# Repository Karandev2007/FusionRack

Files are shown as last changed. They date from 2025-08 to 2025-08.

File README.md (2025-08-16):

<div align="center">
Title Image
</div>

----

<h3 align="center">Zentra / FusionRack</h3>

This is a modern design 2-piece server tower that features total of 4 in-built cooling fans with speed and direction control for more customization, and removable magnetic lid covers for front side.

## Features:
- In-built Cooling System with speed and direction control.
- Removable magnetic lids for easy hardware access.
- Designed for modern era
- Easily assemble or disassemble.
- 2 USFF or TFF mini pc space & a extra plate to attach as you wish for other broads.
--------





<p>


<p>
Fusion360_BamHtervRx
Fusion360_RbzkFNrMxT

----

### Circuit Diagram


----

## CAD


<p>

<p>

<p>

<p>

<p>

## BOM

| Components | Amount | Total Price | Buy Link |
|---|---|---|---|
| 5020 fans | 4 | $4.07 | [link](https://makerbazar.in/products/generic-axial-dc-cooling-fan-blowers?variant=46399947931888) |
| Neodymium Circular Magnet 3mm x 3mm | 24 | $2.20 | [link](https://makerbazar.in/products/neodymium-circular-magnet?variant=47451807875312) |
| 90° L Bracket Right Angle Shape Corner Stand | 8 | $0.92 | [link](https://makerbazar.in/products/right-angle-bracket-iron-angle-code-corner-stand?variant=46436990877936) |
| Ball Caster Wheels | 6 | $1.24 | [link](https://makerbazar.in/products/castor-wheels) |
| Low Cost USB-C wire | 1 | $0.45 | [link](https://makerbazar.in/products/generic-low-cost-type-c-usb-data-cable-black-white) |
| 5V LED strip | 1 | $2.27 | [link](https://amzn.in/d/drIJrVY) |
| PWM Fan Controller | 2 | $3.41 | [link](https://makerbazar.in/products/dc-6v-28v-6v-12v-24v-3a-pwm-dc-motor-speed-controller-forward-reverse-with-switch) |
| Ribbon Cable Wire | 2 | $0.87 | [link](https://makerbazar.in/products/multi-coloured-ribbon-cable-wire?variant=40914910281879) |
| Black Heat Shrink Sleeve Tube (2.5mm) | 1 | $0.091 | [link](https://makerbazar.in/products/heat-shrink?variant=19627635212384) |
| Type-C USB PCB Breakout Board | 1 | $0.22 | [link](https://makerbazar.in/products/type-c-usb-female-to-dip-pcb-breakout-board?variant=46337045299440) |
| KCD1 Big Rocker Switch | 3 | $0.24 | [link](https://makerbazar.in/products/big-rocker-switch-2-leg-spst?variant=46150295814384) |
| Steel Allen Socket Head Nut-Bolt M5 20mm | 2 | $2.17 | [link](https://makerbazar.in/products/stainless-steel-allen-head-nut-bolt-washer-set?variant=44137393783024) |
| Steel Allen Socket Head Nut-Bolt M5 25mm | 2 | $2.52 | [link](https://makerbazar.in/products/stainless-steel-allen-head-nut-bolt-washer-set?variant=45147658322160) |
| Steel Allen Socket Head Nut-Bolt M4 25mm | 1 | $1.09 | [link](https://makerbazar.in/products/stainless-steel-allen-head-nut-bolt-washer-set?variant=44137326838000) |
| buttonhead bolt M3 16mm | 4 | $0.39 | [link](https://novo3d.in/buttonhead-bolt-cs) |
| buttonhead bolt key M3 | 1 | $0.29 | [link](https://novo3d.in/allen-keys) |
| Brass Threaded Round Female Insert Nut | 4 | $0.23 | [link](https://makerbazar.in/products/brass-heat-set-threaded-round-female-insert-nut?variant=44435312083184) |
| JST-SM Male-Female Connectors | 4 | $0.41 | [link](https://makerbazar.in/products/jst-sm-male-and-female-connector-pair-with-wire?variant=47213255065840) |
| Miscs |  | $4 |

Shipping and extra fees: $0.46 (makerbazar) + $0.80 (nova3d) + $0.057 (amazon) = $1.317

Total: $28.44

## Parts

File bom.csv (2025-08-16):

Part Name | Quantity | Cost | Link
5020 fans | 4 | $4.07 | https://makerbazar.in/products/generic-axial-dc-cooling-fan-blowers?variant=46399947931888
Neodymium Circular Magnet 3mm x 3mm | 24 | $2.20 | https://makerbazar.in/products/neodymium-circular-magnet?variant=47451807875312
90° L Bracket Right Angle Shape Corner Stand | 8 | $0.92 | https://makerbazar.in/products/right-angle-bracket-iron-angle-code-corner-stand?variant=46436990877936
Ball Caster Wheels | 6 | $1.24 | https://makerbazar.in/products/castor-wheels
Low Cost USB-C wire | 1 | $0.45 | https://makerbazar.in/products/generic-low-cost-type-c-usb-data-cable-black-white
5V LED strip | 1 | $2.27 | https://amzn.in/d/drIJrVY
PWM Fan Controller | 2 | $3.41 | https://makerbazar.in/products/dc-6v-28v-6v-12v-24v-3a-pwm-dc-motor-speed-controller-forward-reverse-with-switch
Ribbon Cable Wire | 2 | $0.87 | https://makerbazar.in/products/multi-coloured-ribbon-cable-wire?variant=40914910281879
Black Heat Shrink Sleeve Tube (2.5mm) | 1 | $0.091 | https://makerbazar.in/products/heat-shrink?variant=19627635212384
Type-C USB PCB Breakout Board | 1 | $0.22 | https://makerbazar.in/products/type-c-usb-female-to-dip-pcb-breakout-board?variant=46337045299440
KCD1 Big Rocker Switch | 3 | $0.24 | https://makerbazar.in/products/big-rocker-switch-2-leg-spst?variant=46150295814384
Steel Allen Socket Head Nut-Bolt M5 20mm | 2 | $2.17 | https://makerbazar.in/products/stainless-steel-allen-head-nut-bolt-washer-set?variant=44137393783024
Steel Allen Socket Head Nut-Bolt M5 25mm | 2 | $2.52 | https://makerbazar.in/products/stainless-steel-allen-head-nut-bolt-washer-set?variant=45147658322160
Steel Allen Socket Head Nut-Bolt M4 25mm | 1 | $1.09 | https://makerbazar.in/products/stainless-steel-allen-head-nut-bolt-washer-set?variant=44137326838000
buttonhead bolt M3 16mm | 4 | $0.39 | https://novo3d.in/buttonhead-bolt-cs
buttonhead bolt key M3 | 1 | $0.29 | https://novo3d.in/allen-keys
Brass Threaded Round Female Insert Nut | 4 | $0.23 | https://makerbazar.in/products/brass-heat-set-threaded-round-female-insert-nut?variant=44435312083184
JST-SM Male-Female Connectors | 4 | $0.41 | https://makerbazar.in/products/jst-sm-male-and-female-connector-pair-with-wire?variant=47213255065840
Miscs | 1 | $4
Shipping and extra fees |  | $0.46 (makerbazar) + $0.80 (nova3d) + $0.057 (amazon)
Total |  | $28.44

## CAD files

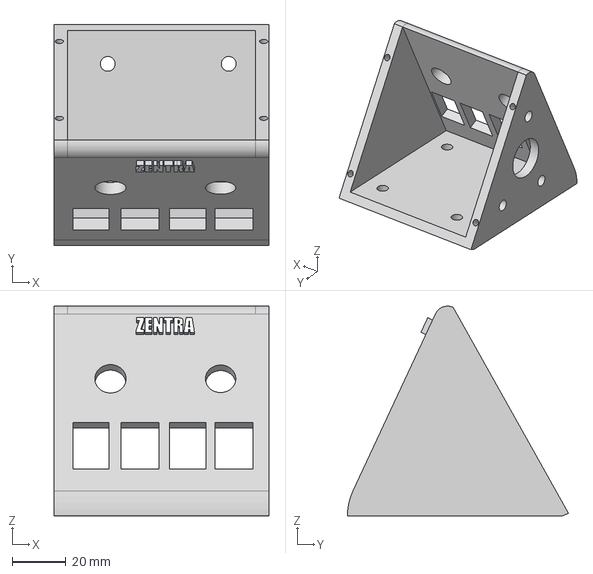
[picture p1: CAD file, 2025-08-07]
CAD/cp_mainbody.step
80.0 x 82.3 x 78.0 mm

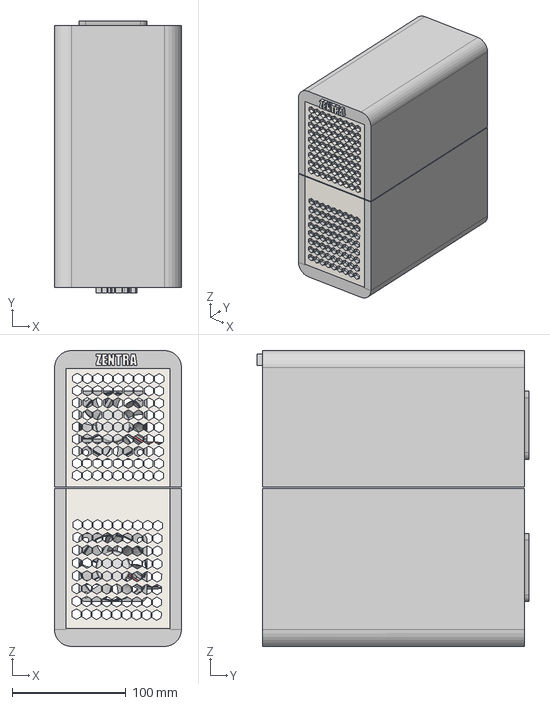
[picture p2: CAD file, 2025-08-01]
CAD/Zentra-assembled.step
111.7 x 239.1 x 259.9 mm

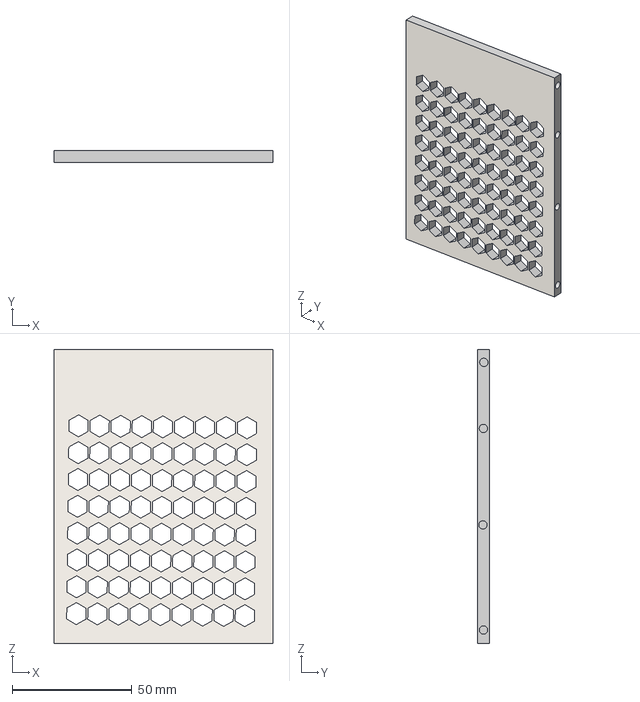
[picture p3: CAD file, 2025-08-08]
CAD/bottom_lid.step
91.5 x 5.00 x 123.0 mm

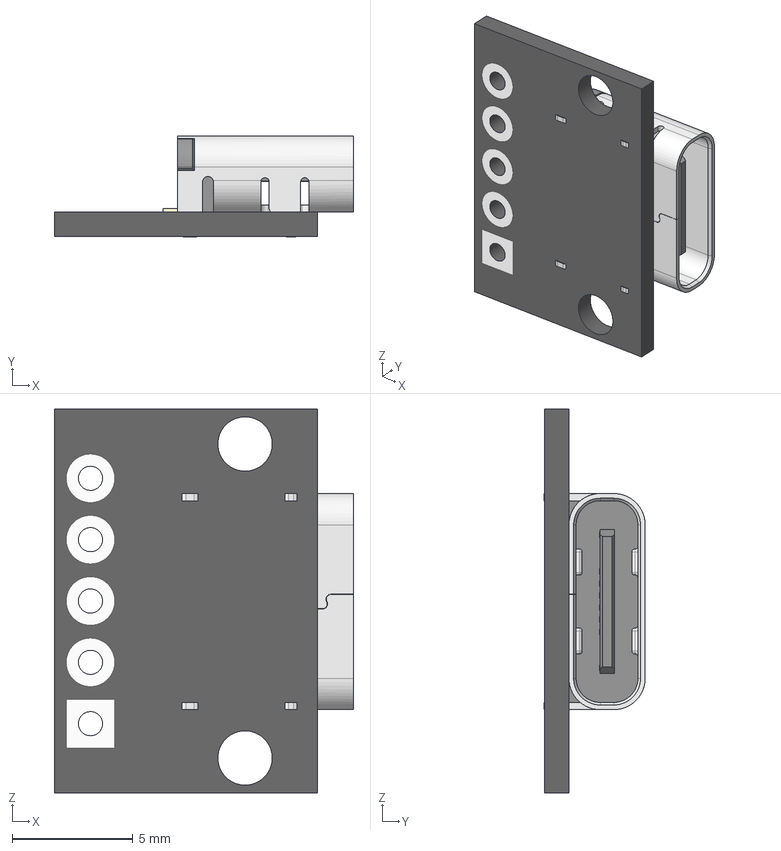
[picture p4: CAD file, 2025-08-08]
CAD/components/PCB USB-C.step
12.4 x 4.20 x 15.9 mm

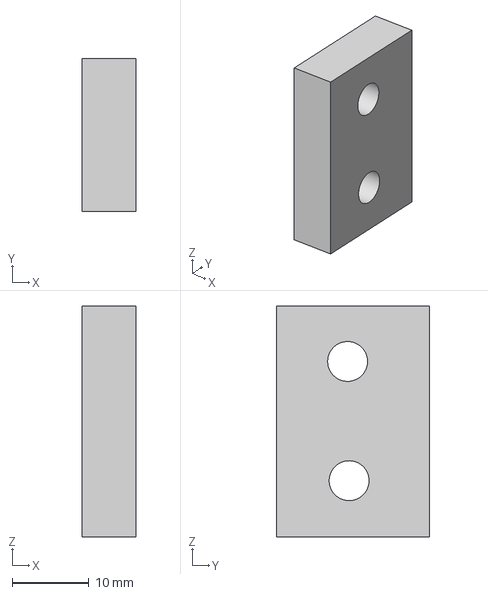
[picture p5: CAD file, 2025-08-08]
CAD/case_join_supports.step
7.00 x 20.0 x 30.1 mm

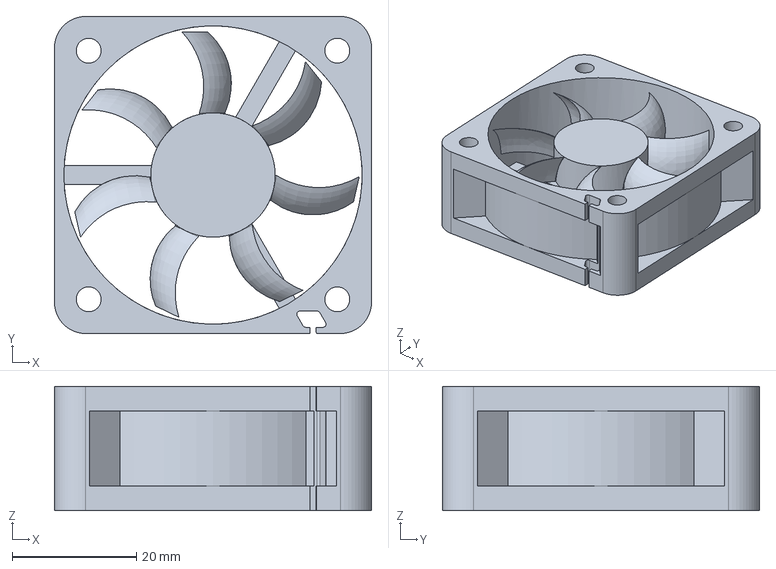
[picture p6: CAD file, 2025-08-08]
CAD/components/GDSTIME 50mm x 50mm x 20mm 12V Brushless Cooling Fan.step
51.0 x 51.0 x 20.0 mm

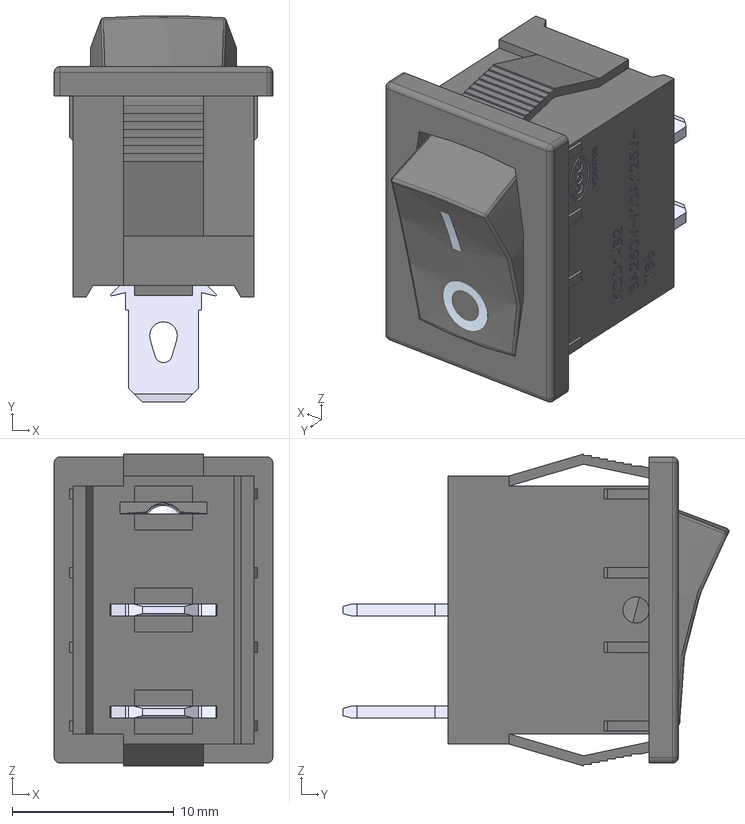
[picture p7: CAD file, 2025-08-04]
CAD/components/KCD1-B2-2P-Off.step
13.5 x 23.8 x 19.3 mm

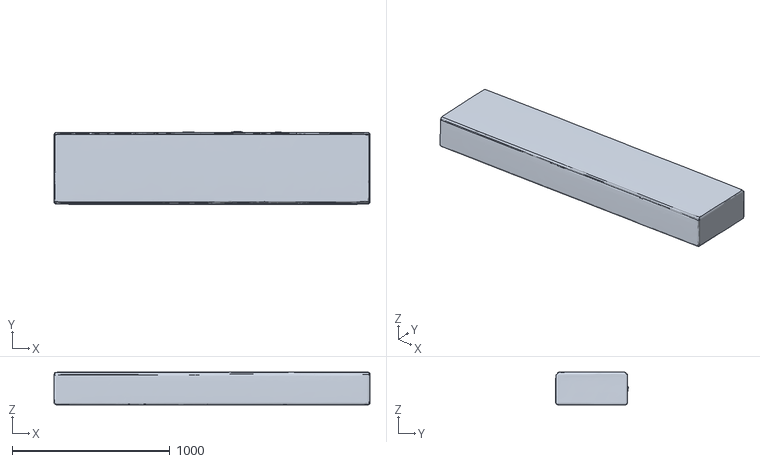
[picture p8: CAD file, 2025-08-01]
CAD/components/USB_Hub_Adapter.stl
2002.4 x 460.7 x 209.0

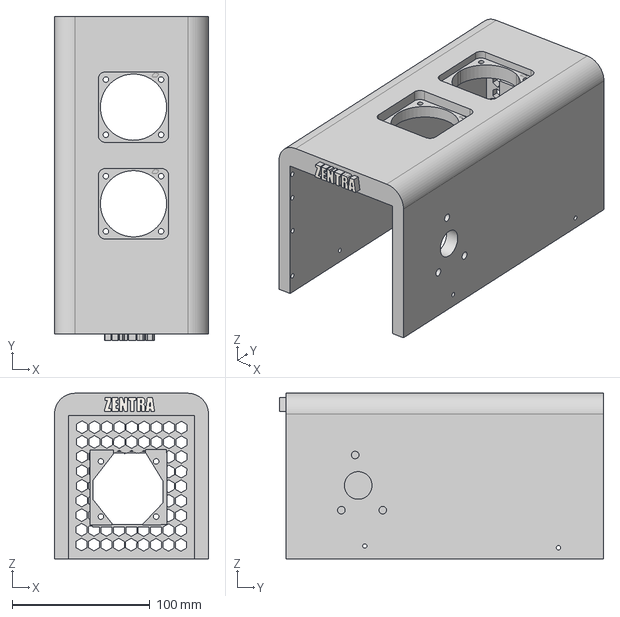
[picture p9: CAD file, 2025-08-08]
CAD/top_body.step
111.6 x 235.1 x 120.0 mm

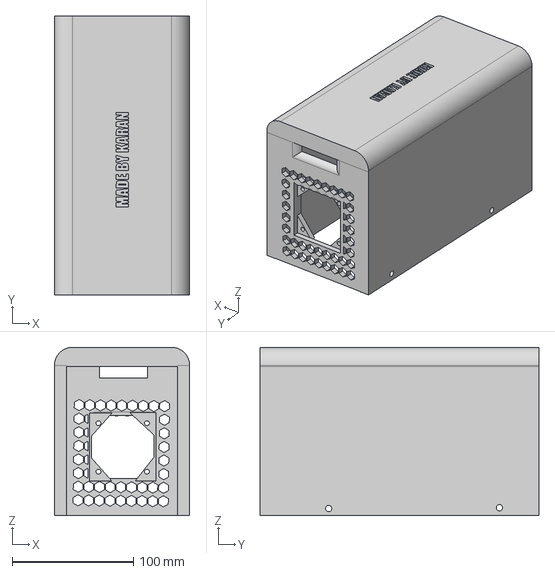
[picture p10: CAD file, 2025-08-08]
CAD/bottom_body.step
111.7 x 230.1 x 138.9 mm

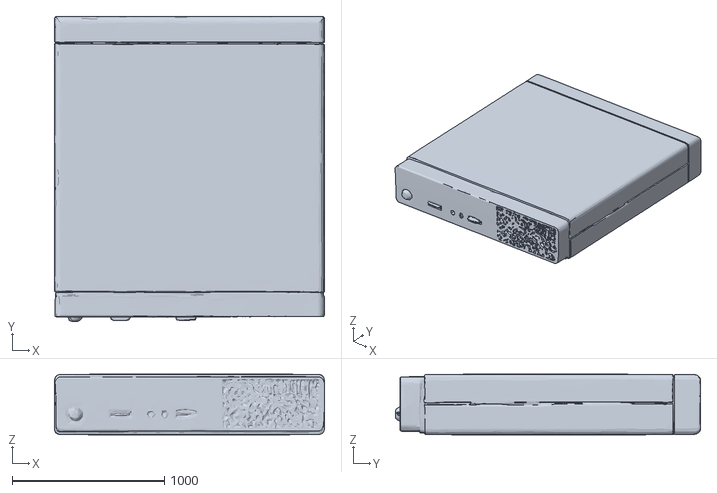
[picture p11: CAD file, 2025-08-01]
CAD/components/ThinkCentre_Mini_Desk_0727185635_texture.stl
1772.3 x 2003.6 x 398.2

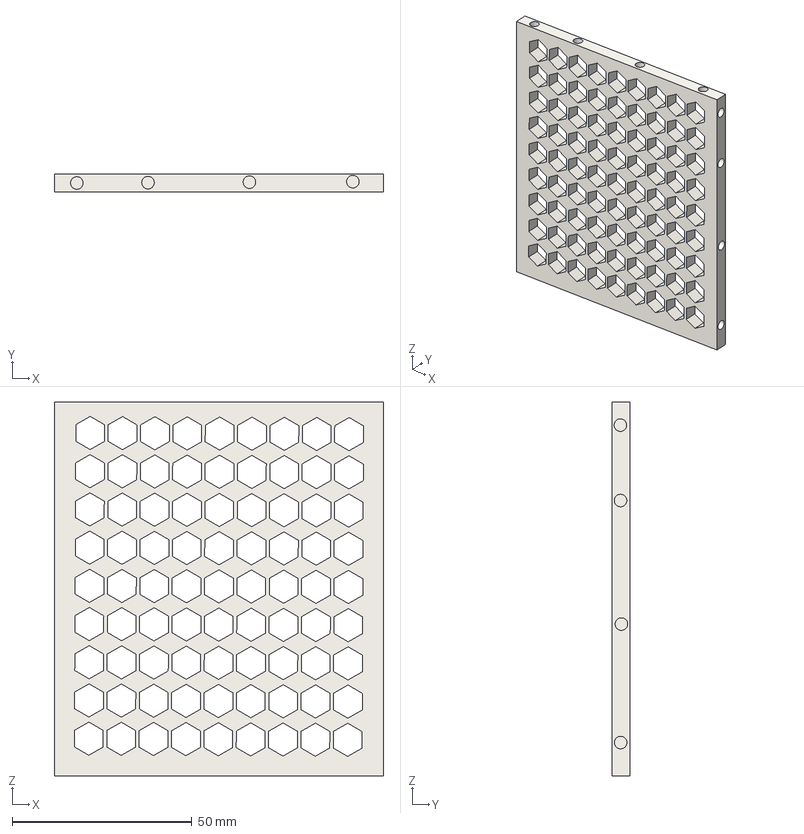
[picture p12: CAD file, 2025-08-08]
CAD/top_lid.step
91.6 x 5.00 x 104.0 mm

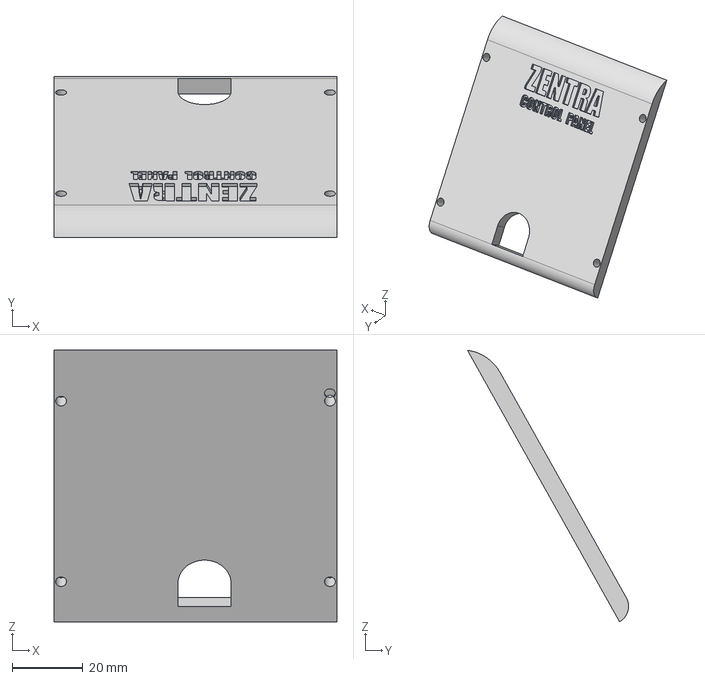
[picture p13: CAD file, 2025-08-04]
CAD/cp_backlid.step
80.0 x 45.6 x 76.8 mm

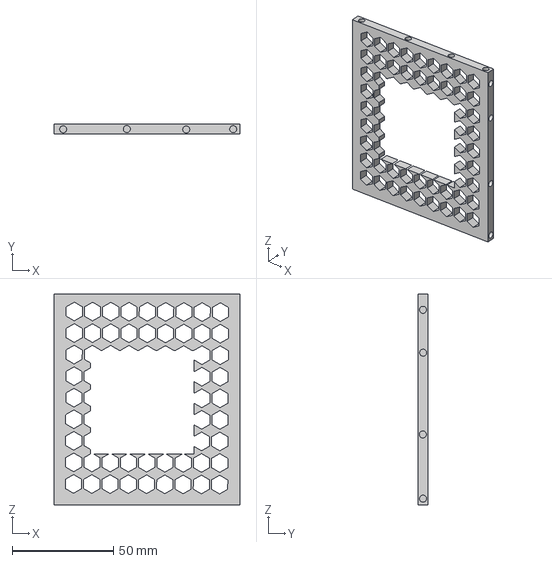
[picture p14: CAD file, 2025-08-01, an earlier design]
CAD/old/upper-back-lid.step
91.6 x 5.00 x 104.0 mm

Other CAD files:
CAD/extra_plate.step
CAD/old/front-upper-lid.step
CAD/old/front-bottom-lid.step
CAD/old/base.step
CAD/old/bottom-back-lid.step
CAD/old/top-body.step

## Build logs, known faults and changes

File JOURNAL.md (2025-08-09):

---
title: "FusionRack / Zentra"
author: "Karan"
description: "a modern design 2-piece server tower that features total of 4 in-built cooling fans with speed and direction control & more."
created_at: "2025-07-27"
---

## TOTAL TIME SPEND: 38h (remake whole once)

Day 1 (27/7/25): (6h)

- made a rough list of components, it was easy as its clear in my mind what i have to make.
- trying some designs with sora and fusion with whats in my mind rn. im planning to have capacity of 2x Raspberry Pi 2W, 2x Raspberry Pi 3,4,5, 1x mini pc, most prob Lenovo Thinkcentre, with proper cooling and a screen to moniter all or specific thats depends on me. so a cheap 3.5 inch display with raspberry pi 2W, fans, switches and more.

skeleton structure image:


- i researched for like more than 3–4 hours on structure, what can be used to make it better, sourced some more parts, tried over 12 designs on frame + case. resolved a problem to divide parts in a manner that they can be printed, because in India we have Bambu Lab A1 Mini and Creality ENDER 3 V3 KE from Printing-Legion, so max plates we can make are 8.66 × 7.08 inches. Mini-PC size alone is 7.20 x 7.05 in, so we are hitting depth only, else is okay. I will try arrangements on a dummy plate of the mini-PC with accurate sizes to get more confirmed about things.

Day 2 (28/7/25): (12h so far)
- discussed some drawbacks and issues with my current designs and materials with shub, and sourced more parts. for the pillars on the edge, i will now use 8mm lead screw stainless steel rods. with them, i will use T8 circular single-start nuts to attach to the plates. im lucky that the filaments in my country are ABS, still i will keep the thickness greater, including cross strips to distribute the weight on the bottom and second middle plate.

i will use honey comb plates with magnets for front and back side of platforms gaps, and on right and left sides a cooling fan with honey comb walls.






- i got to know that Creality from Printing-Legion is not available. so im forced to use Bambu Lab A1 Mini which means 180mm x 180mm / 7*7 inches, means now we cant place our mini-pc also space for rpi's will also be decreased, but i came up with a new plan reference image is below:



- i have restructured whole lab, so it will be increased in height from 12 inches to 16 or 19 depending upon lead screw rods. but we got plus points, as now we will vertically install all pi's and mainly our mini-pc's so we can install like 4 mini pc instead of 1, just need to find a way to fit any minipc on its place maybe using moving mount or something, major companies like HP, lenovo, dell all have almost same size just 2-4 inches difference which can affect for sure.

- here is base i made with 10mm thickness with bottom support stands of 10mm and boundries on all side except front of 5mm, i will add more bottom stands for support as base plate will handle 3-4 mini-pc on it so i dont want that it get broken or bended.



Day 3 (29/7/25): (10h)

- made 3 holes for wiring etc with 30mm diameter and gap btw them of 31mm.
- remove bottom stands from body as it will make printing complex so i made 10mm bottom stands separate.
- sourced components for controller PCB, also [finalized fans](https://makerbazar.in/products/generic-axial-dc-cooling-fan-blowers?variant=46399947931888#product-reviews)

- Made plate 2 and 3 and placed all pis with accurate sizes.



- one more plate completed with objects, usb hub, externals, etc.



- Decreased gaps btw plates for better appearance now it looks like this:



- added 8mm lead screw rods on all 4 corners for support



- added handles of top to pick and and move, as it will not alway have load so adding handles will be useful.



- handles done :D


## some polished structure images :D



- removed handles from top plate cuz it needs alot of support while printing so we have now separate handles here:

 
After attaching them on top using screws:



# Day 4-5 (31/7/25) - (1/8/25): (6h)

- got to know the guy in printing legion left that had required printer for my prints, i checked local 3d printing services which are demanding over 4000inr/45.76$ for a single print that max weights 300g, so i decieded to change whole design to make it printable with the printing legion available printer. here are designs:


- added name on top of project:


- made honey comb grids. this took me straight 30 mins, i did alot of hit and try.


- made another for above section:


- here is full view:


- cut the whole setup into 2 so it can be printed, cuz it the reason im remaking it at last moment to fit in printer size.


- added grids for fans and added fans for presentation:


- added magnets placeholders for front and back plates.

# Day 6 (4/8/25): (4h)

- i have made my mind to keep the control panel for fans and lights, etc separate on a side or top mount control box with size of 80mm*80mm and 5mm thickness.




perfect smooth edges




- made a hole in back for wires.


- added M5 holes for side and top mount


- final control box/panel look:


- added screws for back panel of control panel.



- front view of control panel:


- made holes on side panel of zentra upper body for mounting control panel:
- 

- added hole for wires on zentra and control panel bodies



- made a extra plate for extra broads like rpi etc
Fusion360_tLGu8A8jJq
Fusion360_mWScv6MAmZ
Fusion360_chnrRIt6cY
- made holes for M5 screws:


### FINAL RENDERED LOOK:


- updated BOM and Readme.

# Day 7 (8/8/25): (2h)

- added more stable support for fans on lids
- made space for fans on top of case with screw holes.
  
Fusion360_hxXb0bYYCC

- added extra space on extra plate for back lid fan.
- made space for switches and knobs in control panel

Fusion360_5w3wfJcZCi

- updated BOM and Readme.
- made support for fans and merged back lids into body.
Fusion360_pwB9NhmAKU
- increased size of M3 holes to M5 for better stablity:
Fusion360_t8cnQmieDk
- did some small fixes
- updated BOM and readme for images.
